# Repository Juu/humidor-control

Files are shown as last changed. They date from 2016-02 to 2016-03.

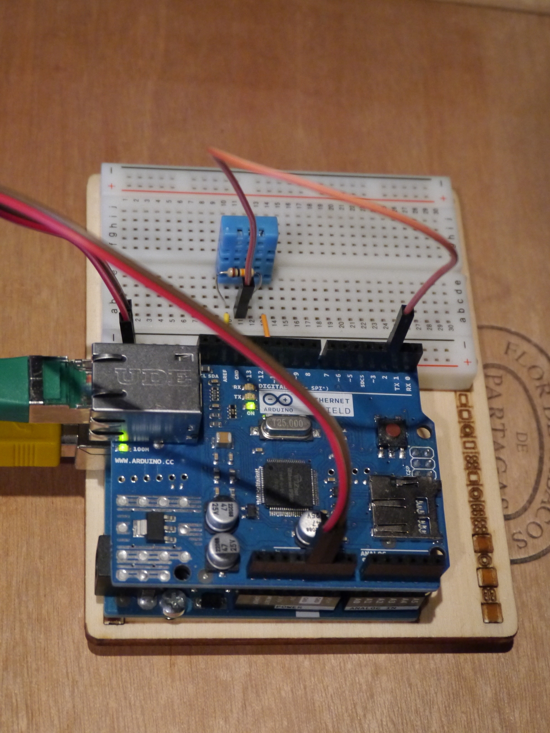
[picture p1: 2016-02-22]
arduino/board_v1.0.jpg

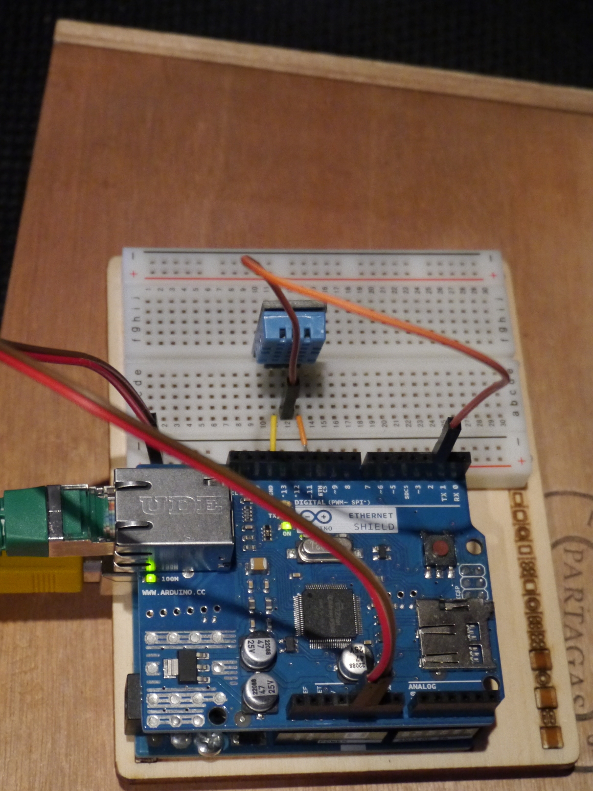
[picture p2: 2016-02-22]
arduino/board_v1.1.jpg

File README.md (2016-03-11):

# humidor-control
Watch humidity, temperature and other events from your humidor on a web interface, all measured by an Arduino.

## Arduino part
Wire up your circuit as shown in wiring* scheme with components listed in hardware.txt.

Review configuration constants at the beginning of the sketch (serial debugging, sensor, button, network), then upload it to your ESP8266.

This version uses a ESP-01 wifi module to manage logic and networking.
V1 was based on an Arduino Uno and ethernet shield.

## Web server part (Go)

go-sqlite3 library must be installed:

    go install github.com/mattn/go-sqlite3
Other way to get it, there is for example a debian package:

    apt-get install golang-github-mattn-go-sqlite3-dev

First, start with generating your "api key":

    go run createApiKey.go

Then launch the server:

    go run websvr.go

And open your browser at http://localhost:1664

### How to get test data without an Arduino

The repository contains a database with some dummy data in file `data.db-test_database`. Just rename it to `data.db`

    mv data.db-test_database data.db

You can also use script `sendTestData.go` to fill your database with custom data (see comments in source code for optional parameters):

    go run sendTestData.go

Alternately, send HTTP GET requests by yourself to `http://localhost:1664/add` (assuming standard host and port) with following mandatory parameters:
- apiKey: The "api key" created by createApiKey.go and stored in apikey.txt
- d: Unix Timestamp
- t: Temperature (float)
- h: humidity (float)
- e: event (can be "do" or "dc")

Params d, t, h and e can be repeated n times to save n measurements in the db

Params t, h and e can be empty but should exist, particularly when the query holds several measurements.

Example:

    http://localhost:1664/add?apiKey=fbc6caf152b8016f125364942c09775b4b12d995&d=1430656115&t=19.5&h=65&e=

## Limitations

Only the "api key" currently prevents anybody to send whatever data they want to your server, but as everything is in cleartext in the query string, sniffing the requests between Arduino and the server is enough. Using this outside your local network is at your own risk.

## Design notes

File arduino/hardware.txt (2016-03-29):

Board:
- 1x ESP-01 module (based on ESP8266 chip)
- 2x 1kΩ pull-up resistors for RST and CH_PD pins

Power supply:
- 1x LD1117V33 voltage regulator
- 1x diode 1N4001 series (just to make sure the input 12V is properly wired)
- 1x 100nF capacitor
- 1x 10µF capacitor

Humidity/temperature sensor:
- 1x DHT11 humidity sensor (accuracy: +-5% RH ; +-2°C)
- 1x 10kΩ or 5kΩ resistor (as pull-up)

Detecting door opening:
- 1x or more pushbutton (wired in parallel) open when humidoors are closed
- 1x NPN bipolar transistor (used with the 3 resistors to act as a NOT logic gate to keep ESP8266's GPIO_2 input high on startup)
- 1x 33Ω resistor
- 2x 100Ω resistor

To light up external 12V leds on door opening:
- 1x n-type MOSFET IRF520

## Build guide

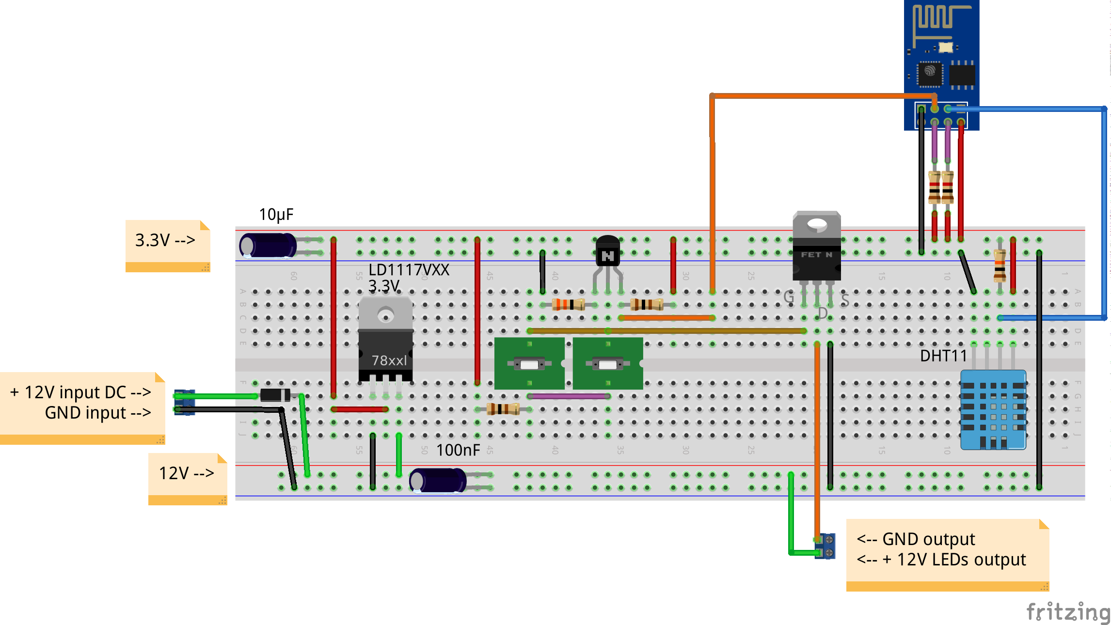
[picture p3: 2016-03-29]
arduino/wiring_bb.png

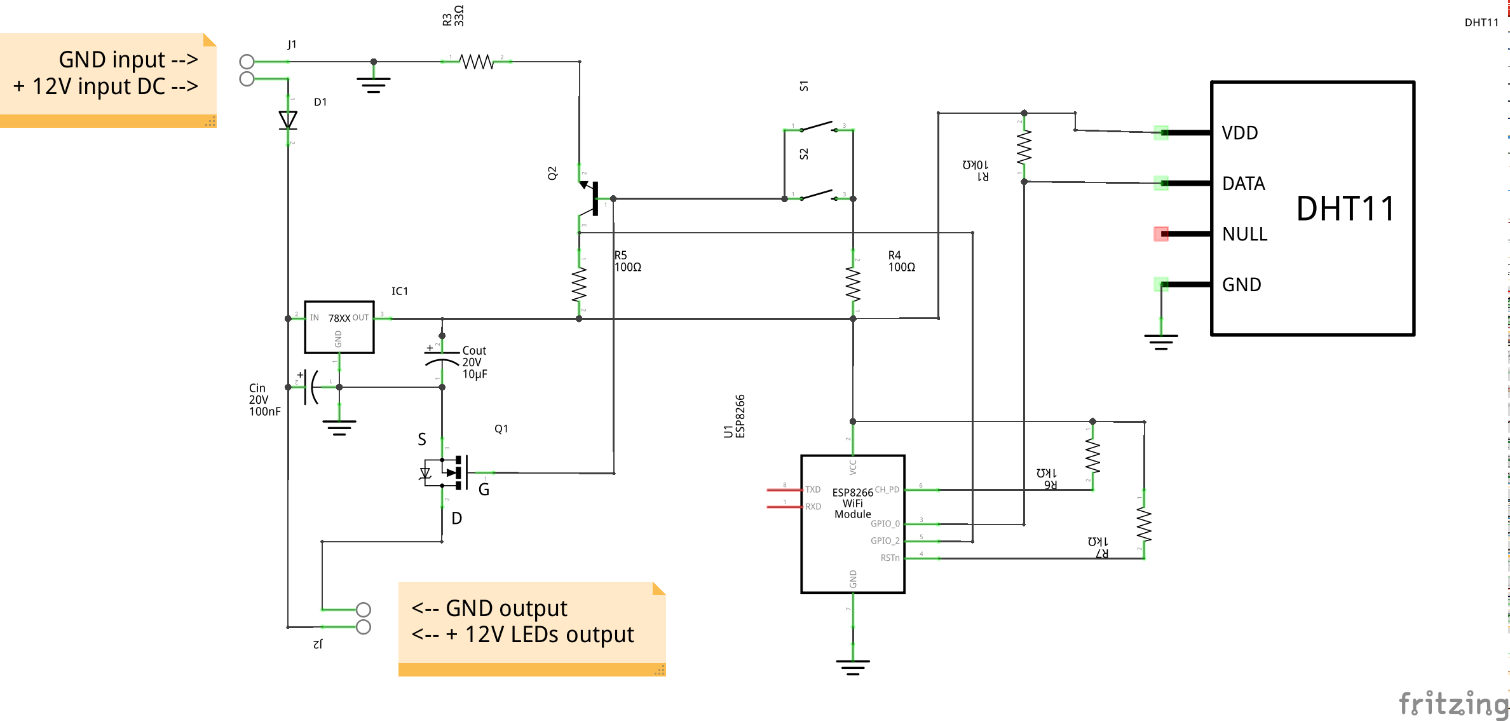
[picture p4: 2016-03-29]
arduino/wiring_schem.png

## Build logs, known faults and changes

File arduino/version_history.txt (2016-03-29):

v2.0
Replaces Arduino and shield with an ESP-01 module
Added a 3.3V voltage regulator to supply the complete setup with the 12V input

v1.3
Light up the humidor (w/ external 12V leds) when door is open.
Arduino can be powered with external 12V DC input

v1.2
Added buttons for sensing doors opening

v1.1
Replaced sensor with a DHT11 module with built-in 5k resistor

v1.0
Using an Arduino Uno and an ethernet shield
Measuring with a DHT11 sensor

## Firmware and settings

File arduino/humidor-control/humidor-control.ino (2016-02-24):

#include <SPI.h>
#include <Ethernet.h>
#include <EthernetUdp.h>
#include <DHT.h>


// Set to true for debug messages to Serial Monitor
#define DEBUG false

// ************** Humidity/temperature sensor configuration

// Time interval between each temperature/humidity measurements (seconds)
#define MEASUREMENT_INTERVAL      5*60 // 5 minutes

// Temperature and humidity values adjustment, if your sensor values are below (adjust with a positive integer) or above (negative int) reality.
// For no adjustment, set to 0
#define TEMPERATURE_ADJUSTMENT    2
#define HUMIDITY_ADJUSTMENT       12

// Humidity sensor pin and type
#define DHTPIN 2     // what digital pin we're connected to
// Uncomment whatever type you're using!
#define DHTTYPE DHT11   // DHT 11
//#define DHTTYPE DHT22   // DHT 22  (AM2302), AM2321
//#define DHTTYPE DHT21   // DHT 21 (AM2301)


// ************** Doors open/closed button configuration

#define BUTTONPIN                 3


// ************** Ethernet configuration - global

// Enter a MAC address for your controller below.
// Newer Ethernet shields have a MAC address printed on a sticker on the shield
byte mac[] = {
  //0xDE, 0xAD, 0xBE, 0xEF, 0xFE, 0xED
  0x90, 0xA2, 0xDA, 0x0F, 0x13, 0x11
};

// Set the static IP address to use if the DHCP fails to assign
IPAddress ip(192, 168, 1, 76);


// ************** Ethernet configuration - time synchronization

// Time interval between each time synchro from NTP server (seconds)
#define TIME_SYNCHRO_INTERVAL     5*60 //24*3600 // each 24 hours

unsigned int localPort = 8888;       // local port to listen for UDP packets
const char timeServer[] = "time.nist.gov"; // time.nist.gov NTP server


// ************** Ethernet configuration - Web server

// IP or DNS name of the stats server
IPAddress server(192, 168, 1, 4);
//char server[] = "myStatServer.net";

// Port of the stats server. Default is 1664
int port = 1664;

#define API_KEY "2e4ca51efbeee9d63ae89480b2f81f8615c23979"


// ********** End of configuration **********


#if DEBUG
  #define debug(s)    Serial.print(s);
  #define debugln(s)  Serial.println(s);
#else
  #define debug(s)    
  #define debugln(s)  
#endif

// Initialize DHT object
DHT dht(DHTPIN, DHTTYPE);

int lastButtonStatus = LOW;

const int NTP_PACKET_SIZE = 48; // NTP time stamp is in the first 48 bytes of the message
byte packetBuffer[NTP_PACKET_SIZE]; //buffer to hold incoming and outgoing packets

// A UDP instance to let us send and receive packets over UDP
EthernetUDP Udp;

// Initialize the Ethernet client library
// with the IP address and port of the server
// that you want to connect to (port 80 is default for HTTP):
EthernetClient client;

unsigned long lastStartTime = 0;
unsigned long lastSynchroTime = 0;
unsigned long lastMeasurementTime = 0;

struct measurement {
  unsigned long time;
  int temperature;
  int humidity;
  int doorOpening;
  int doorClosing;
};


void setup() {
  // DHT sensor init
  dht.begin();

  // initialize the pushbutton pin as an input
  pinMode(BUTTONPIN, INPUT);
  
  #if DEBUG
    // Serial used for debug
    Serial.begin(9600);
    while (!Serial) {
      ; // wait for serial port to connect. Needed for native USB port only
    }
  #endif
  
  // start Ethernet and UDP
  if (Ethernet.begin(mac) == 0) {
    debugln("Failed to configure Ethernet using DHCP. Trying with static IP...");
    // try to configure using IP address instead of DHCP:
    Ethernet.begin(mac, ip);
  }
  Udp.begin(localPort);

  debug("My IP address: ");
  debugln(Ethernet.localIP());

  delay(1000);
}

void loop() {

  unsigned long time = getTime();

  int buttonStatus = digitalRead(BUTTONPIN);
  if (buttonStatus != lastButtonStatus) {
    printTime(time);
    debug("Button status changed to: ")
    debugln(buttonStatus);

    sendMeasurement({time, 0, 0, buttonStatus==HIGH, buttonStatus==LOW});

    lastButtonStatus = buttonStatus;
  }
  
  // Do a new temperature and humidity measurement for the first time or if interval since last one reached MEASUREMENT_INTERVAL value
  if (time - lastMeasurementTime >= MEASUREMENT_INTERVAL) {
    lastMeasurementTime = time;
    printTime(time);
    
    int h = dht.readHumidity() + HUMIDITY_ADJUSTMENT;
    int t = dht.readTemperature() + TEMPERATURE_ADJUSTMENT;
    debug("Humidity: ");
    debug(h);
    debug(" %\t");
    debug("Temperature: ");
    debug(t);
    debug(" *C \n");

    sendMeasurement({time, t, h, false, false});
    
  }
  
  delay(1000);
}

/**
 * Returns current time. Get it from NTP server if needed.
 */
unsigned long getTime() {
  unsigned long currStartTime = millis() / 1000;
  
  // Synchro time from NTP server :
  // - if function is called for the first time 
  // - if interval since last synchro is greater reached TIME_SYNCHRO_INTERVAL value
  if (!lastSynchroTime || currStartTime - lastStartTime >= TIME_SYNCHRO_INTERVAL) {
    lastSynchroTime = getTimeFromNTP();
    lastStartTime = currStartTime;
  }

  unsigned long currentTime = currStartTime - lastStartTime + lastSynchroTime;
  
  return currentTime;
}

/**
 * Returns current time from NTP server.
 */
unsigned long getTimeFromNTP() {
  unsigned long epoch = 0;
  sendNTPpacket(timeServer); // send an NTP packet to a time server

  // wait to see if a reply is available
  delay(1000);
  if (Udp.parsePacket()) {
    // We've received a packet, read the data from it
    Udp.read(packetBuffer, NTP_PACKET_SIZE); // read the packet into the buffer

    // the timestamp starts at byte 40 of the received packet and is four bytes,
    // or two words, long. First, extract the two words:

    unsigned long highWord = word(packetBuffer[40], packetBuffer[41]);
    unsigned long lowWord = word(packetBuffer[42], packetBuffer[43]);
    // combine the four bytes (two words) into a long integer
    // this is NTP time (seconds since Jan 1 1900):
    unsigned long secsSince1900 = highWord << 16 | lowWord;
    
    // now convert NTP time into everyday time:
    // Unix time starts on Jan 1 1970. In seconds, that's 2208988800:
    const unsigned long seventyYears = 2208988800UL;
    // subtract seventy years:
    epoch = secsSince1900 - seventyYears;
  }
  // Ethernet.maintain();

  return epoch;
}

/**
 * Debug function to print time in a human-readable way
 */
void printTime(unsigned long epoch) {
  #if DEBUG
    // print the hour, minute and second:
    Serial.print("The UTC time is ");       // UTC is the time at Greenwich Meridian (GMT)
    Serial.print((epoch  % 86400L) / 3600); // print the hour (86400 equals secs per day)
    Serial.print(':');
    if (((epoch % 3600) / 60) < 10) {
      // In the first 10 minutes of each hour, we'll want a leading '0'
      Serial.print('0');
    }
    Serial.print((epoch  % 3600) / 60); // print the minute (3600 equals secs per minute)
    Serial.print(':');
    if ((epoch % 60) < 10) {
      // In the first 10 seconds of each minute, we'll want a leading '0'
      Serial.print('0');
    }
    Serial.println(epoch % 60); // print the second
  #endif
}


// send an NTP request to the time server at the given address
void sendNTPpacket(const char * address) {
  // set all bytes in the buffer to 0
  memset(packetBuffer, 0, NTP_PACKET_SIZE);
  // Initialize values needed to form NTP request
  // (see URL above for details on the packets)
  packetBuffer[0] = 0b11100011;   // LI, Version, Mode
  packetBuffer[1] = 0;     // Stratum, or type of clock
  packetBuffer[2] = 6;     // Polling Interval
  packetBuffer[3] = 0xEC;  // Peer Clock Precision
  // 8 bytes of zero for Root Delay & Root Dispersion
  packetBuffer[12]  = 49;
  packetBuffer[13]  = 0x4E;
  packetBuffer[14]  = 49;
  packetBuffer[15]  = 52;

  // all NTP fields have been given values, now
  // you can send a packet requesting a timestamp:
  Udp.beginPacket(address, 123); // NTP requests are to port 123
  Udp.write(packetBuffer, NTP_PACKET_SIZE);
  Udp.endPacket();
}


void sendMeasurement(measurement m) {

  client.stop();

  // Connect to stats server
  if (client.connect(server, port)) {
    debugln("Connected to web server");
    // Make a HTTP request:

    char req[256];
    sprintf(req, "GET /add?apiKey=%s&d=%lu&t=%d&h=%d&e=%s HTTP/1.1", API_KEY, m.time, m.temperature, m.humidity, m.doorOpening ? "DO" : (m.doorClosing ? "DC" : "0"));
    debugln(req);
    client.println(req);
    client.println("Host: myStatServer.net");
    client.println("User-Agent: arduino-ethernet");
    client.println("Connection: close");
    client.println();
  } else {
    // if you didn't get a connection to the server:
    debugln("connection failed");

  }

  displayServerResponse();
  
}

/**
 * Debug function to display stats server response code
 */
void displayServerResponse() {
  #if DEBUG
    // if there are incoming bytes available
    // from the server, read them and print them:
    debug("Server responded: ");
    
    char resp[100];
    //debugln(sizeof(resp));
    int i = 0;
    while (i < (int)sizeof(resp) - 1 && resp[i-1] != '\n' && client.available()) {
      resp[i++] = client.read();
    }
    resp[i] = '\0';
    
    debugln(resp);

  #endif
}

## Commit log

2016-02-21 Wiring scheme with humidity sensor
    [wiring.fzz]
2016-02-22 Arduino code
2016-02-22 Add unit on the y-axis values
2016-02-22 Better graph display
    Removed alignTicksWithAxis to show better human-readable humidity values on y-axis
2016-02-23 Add Arduino code to manage door events
2016-02-28 Better schematic and png export
    [wiring.fzz]
2016-02-28 Add pushbuttons to wiring scheme
    [wiring.fzz]
2016-02-28 Add resistors function in hardware list
2016-03-08 Add external 12V power supply and LEDs
    [wiring.fzz]
2016-03-10 identify mosfet pins
    [wiring.fzz]
2016-03-10 Fix leds wiring (before drain)
    [wiring.fzz]
2016-03-11 Update wiring to v2
    [wiring.fzz]
2016-03-15 Wiring connections fixes and schematic
    [wiring.fzz]
2016-03-29 Removed one useless wire in bb view
    [wiring.fzz]
2016-03-29 Replace LD1117 Cin capacitor val to 100nF to match with datasheet recommendation
    [wiring.fzz]
